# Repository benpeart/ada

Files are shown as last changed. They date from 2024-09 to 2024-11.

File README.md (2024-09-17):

# Ada
A friendly balancing robot

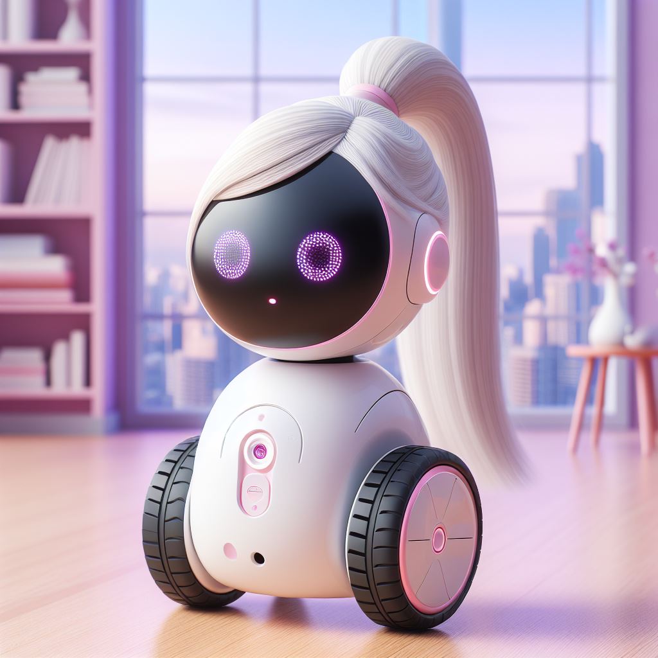
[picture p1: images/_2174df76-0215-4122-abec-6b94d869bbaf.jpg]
Ada, the friendly balancing robot


# MVP Features
* Cute - call it Ada (Lovelace)
* Two wheeled balancing robot
* Drive with a game controller
# V.Next Features
* Track person and follow them around
* Face recognition – “Hi Mom!”
* speak name, verbal interface (integrate with CoPilot/ChatGPT?)
* WebUI that allows manual navigation (virtual joystick and object avoidance)
* WebUI that shows LIDAR map with ability to tell them to go to a specific location

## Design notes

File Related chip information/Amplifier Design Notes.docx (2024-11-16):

HI-FI LM386 Stereo Amplifier : 3 Steps (with Pictures) - Instructables (https://www.instructables.com/HI-FI-LM386-Stereo-Amplifier/)

Simple Arduino Audio/Music Player with SD Card (circuitdigest.com) (https://circuitdigest.com/microcontroller-projects/arduino-audio-music-player)

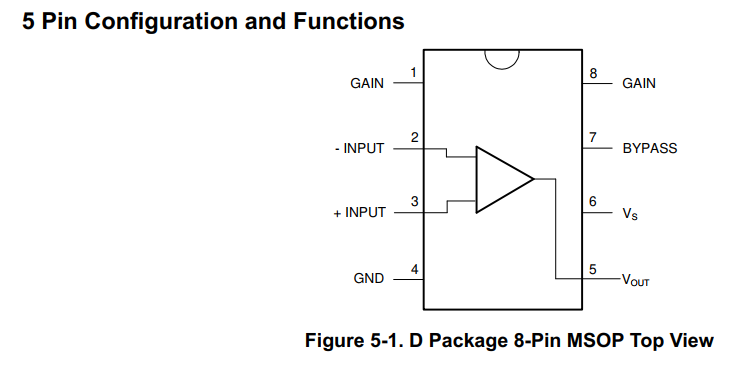
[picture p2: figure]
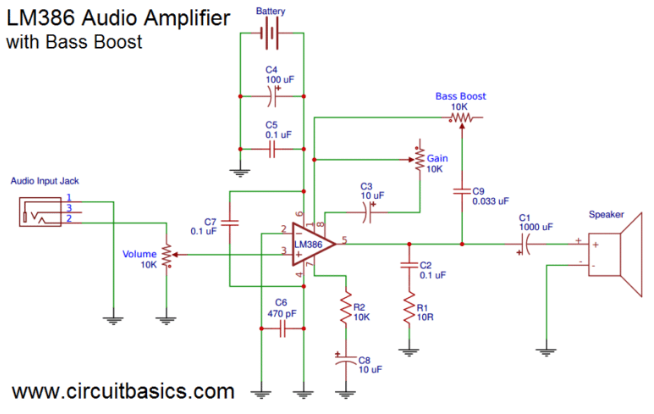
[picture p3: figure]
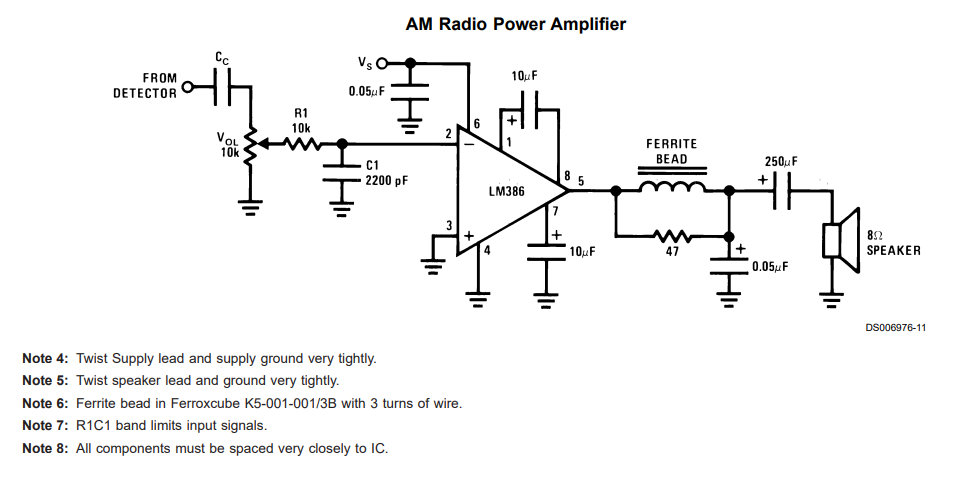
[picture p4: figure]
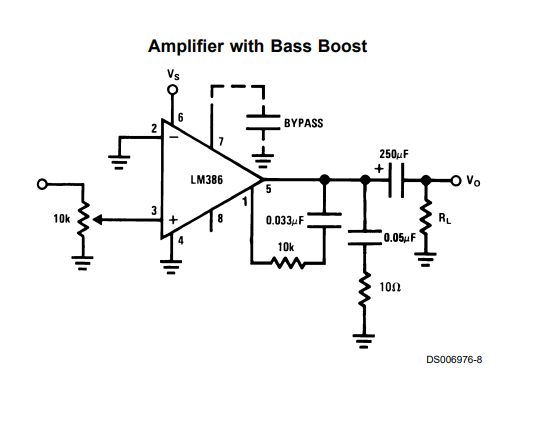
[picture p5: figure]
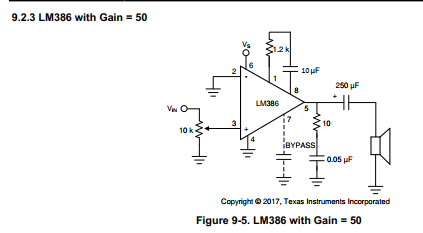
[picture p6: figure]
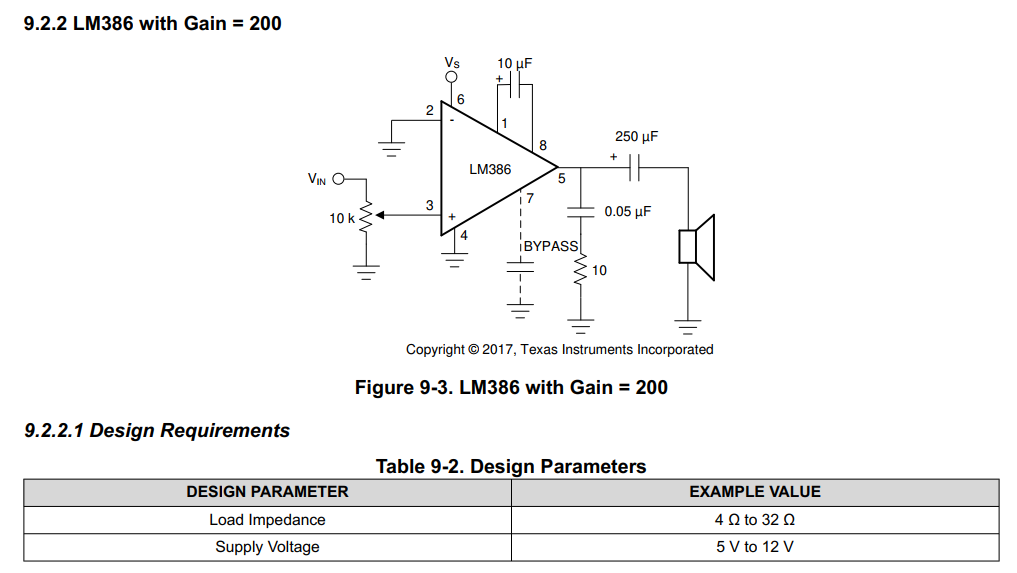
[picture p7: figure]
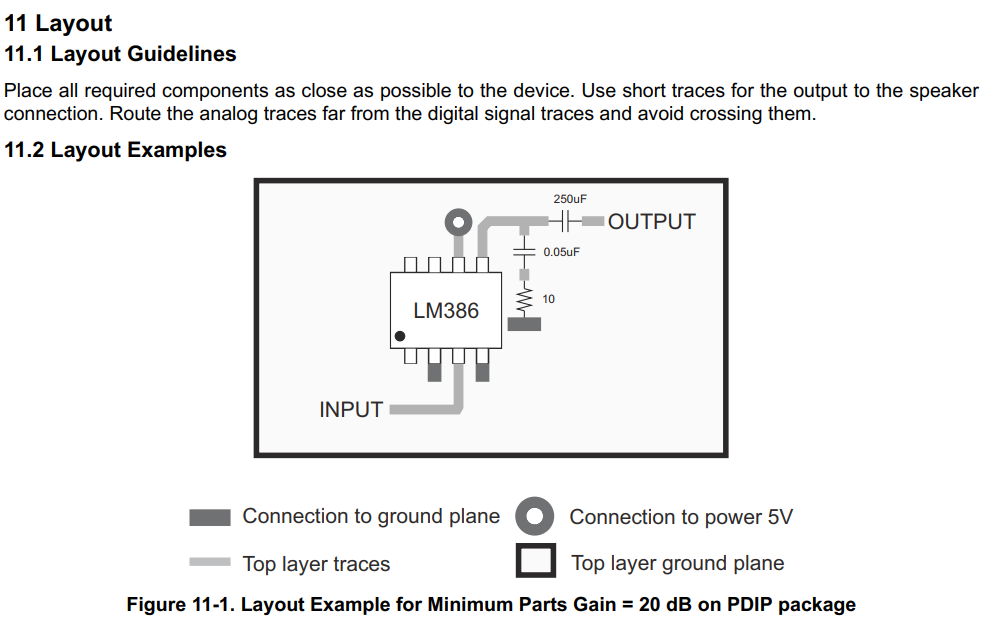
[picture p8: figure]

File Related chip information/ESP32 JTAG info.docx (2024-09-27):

## Wiring Connections (https://docs.platformio.org/en/latest/plus/debug-tools/esp-prog.html)

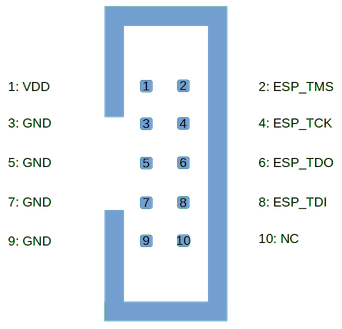
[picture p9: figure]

ESP-Prog JTAG 10-Pin Connector | PCB Header Pin | JTAG Signal | ESP32 Pin | Description
6 | 6 | TDO | GPIO15 | Test Data Out
2 | 5 | TMS | GPIO14 | Test Mode State
8 | 4 | TDI | GPIO12 | Test Data In
3 | 3 | GND | GND | Digital ground
4 | 2 | TCK | GPIO13 | JTAG Return Test Clock
1 | 1 | VDD | VDD | Positive Supply Voltage — Power supply for JTAG interface drivers

## USB configuration

1. After wiring it up, plug the ESP-Prog debugger board into a free USB port on your PC
2. Run Zadig.exe and check the “Options/List All Devices” option
3. Find “Dual RS232-HS (Interface 0)” and replace the driver with “WinUSB (v6.1.7600.16385)”
4. Find “Dual RS232-HS (Interface 0)” and replace the driver with “WinUSB (v6.1.7600.16385)”

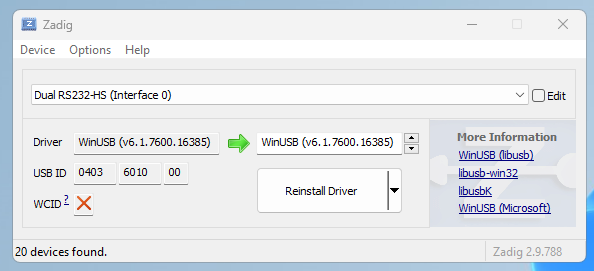
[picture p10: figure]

Add the following lines to platform.ini:

debug_tool = esp-prog

debug_init_break = tbreak setup

## Notes

Jumpers on the ESP-Prog board allow you to choose 3.3V or 5V output. It should match the power pin VDD is connected to on the ESP32.

To get it to update and debug successfully, I didn’t plug in the JTAG power wire to the ESP32 (the orange wire on pin closest to USB port). I can then plug in the regular USB port from ESP32 to PC which powers the ESP32.

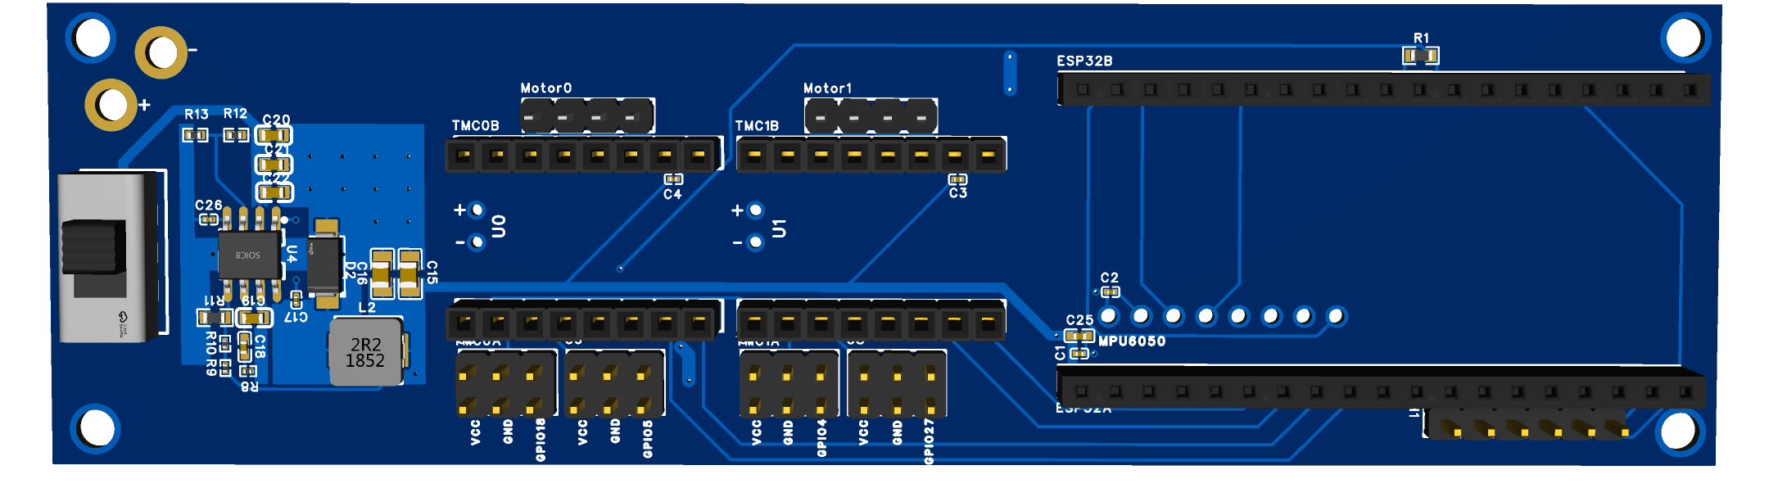
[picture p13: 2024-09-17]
Hardware/Ada PCB.png

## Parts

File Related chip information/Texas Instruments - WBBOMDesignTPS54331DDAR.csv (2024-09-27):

Part | Manufacturer | Part Number | Quantity | Price ($) | Footprint (mm²) | Description
Cboot | MuRata | GRM155R71A104KA01D | 1 | 0.01 | 3 | Cap: 100 nF Total Derated Cap: 100 nF VDC: 10 V ESR: 1 mΩ Package: 0402
Ccomp | TDK | C2012C0G1H272J060AA | 1 | 0.03 | 6.75 | Cap: 2.7 nF Total Derated Cap: 2.7 nF VDC: 50 V ESR: 0 Ω Package: 0805
Ccomp2 | Yageo | CC0805JRNPO9BN100 | 1 | 0.01 | 6.75 | Cap: 10 pF Total Derated Cap: 10 pF VDC: 50 V ESR: 0 Ω Package: 0805
Cin | TDK | C3225X7R1H106M250AC | 2 | 0.27 | 14.7 | Cap: 10 µF Total Derated Cap: 10 µF VDC: 50 V ESR: 1 mΩ Package: 1210
Cout | MuRata | GRM32ER61C476KE15L | 2 | 0.17 | 14.7 | Cap: 47 µF Total Derated Cap: 63 µF VDC: 16 V ESR: 3.04 mΩ Package: 1210
Css | MuRata | GRM033R71A822KA01D | 1 | 0.01 | 2.08 | Cap: 8.2 nF Total Derated Cap: 8.2 nF VDC: 10 V ESR: 1 mΩ Package: 0201
D1 | Fairchild Semiconductor | FSV360FP | 1 | 0.13 | 13.16 | Type: Schottky VRRM: 60 V Io: 3 A
L1 | Coilcraft | MSS1038-123MLB | 1 | 0.62 | 151.28 | L: 12 µH DCR: 36.9 mΩ IDC: 4 A
Rcomp | Vishay-Dale | CRCW040213K7FKED | 1 | 0.01 | 3 | Resistance: 13.7 kΩ Tolerance: 1.0% Power: 63 mW
Rfbb | Vishay-Dale | CRCW04021K96FKED | 1 | 0.01 | 3 | Resistance: 1.96 kΩ Tolerance: 1.0% Power: 63 mW
Rfbt | Vishay-Dale | CRCW040210K2FKED | 1 | 0.01 | 3 | Resistance: 10.2 kΩ Tolerance: 1.0% Power: 63 mW
U1 | Texas Instruments | TPS54331DDAR | 1 | 0.53 | 55.2

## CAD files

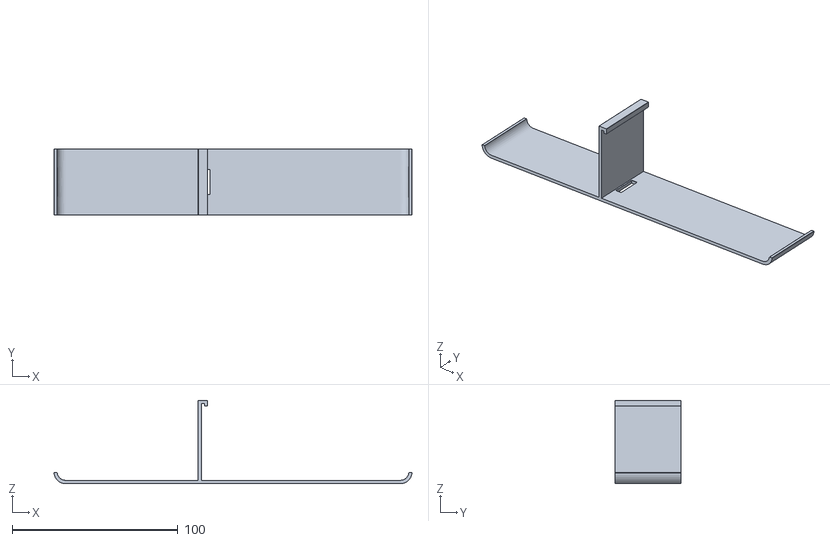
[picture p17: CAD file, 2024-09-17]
Hardware/Kickstand v13.stl
215.9 x 40.0 x 50.2

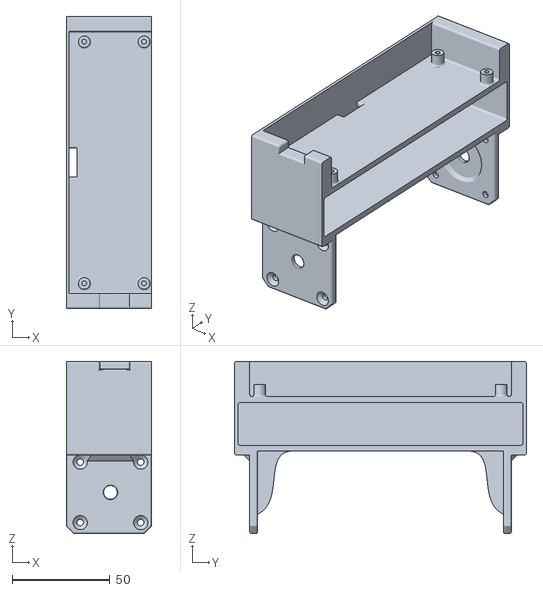
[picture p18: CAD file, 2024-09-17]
Hardware/Ada.stl
43.8 x 149.6 x 88.3

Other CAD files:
Hardware/Ada.f3d
Hardware/Frame.f3d
Hardware/Wheel.f3d

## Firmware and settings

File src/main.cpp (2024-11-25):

/*
A high speed balancing robot, running on an ESP32.

Forked and highly modified by Ben Peart. See http://github.com/benpeart/ada

Wouter Klop
wouter@elexperiment.nl
For updates, see elexperiment.nl

Use at your own risk. This code is far from stable.

This work is licensed under the Creative Commons Attribution-ShareAlike 4.0 International License.
To view a copy of this license, visit http://creativecommons.org/licenses/by-sa/4.0/
This basically means: if you use my code, acknowledge it.
Also, you have to publish all modifications.

*/

#include <Arduino.h>
#include "globals.h"
#include <gyro.h>
#include "fsm.h"
#ifdef TMC2209
#include <TMCStepper.h>
#endif // TMC2209
#include "led.h"
#include "wificonnection.h"
#include "webserver.h"
#ifdef INPUT_PS3
#include "ps3.h"
#endif // INPUT_PS3
#ifdef INPUT_XBOX
#include "xbox.h"
#endif // INPUT_XBOX
#include "debug.h"

// TMC2209 Stepper driver
#ifdef TMC2209
#define DRIVER_ADDRESS_LEFT 0b00  // TMC2209 Driver address according to MS1=LOW and MS2=LOW
#define DRIVER_ADDRESS_RIGHT 0b01 // TMC2209 Driver address according to MS1=HIGH and MS2=LOW

#define SERIAL2_PORT Serial2 // TMC2208/TMC2224 HardwareSerial port
#define SERIAL_BAUD_RATE 500000

#define MAX_CURRENT 2000 // in mA; should match capabilities of stepper motor
#define R_SENSE 0.11f    // Match to your driver
                         // SilentStepStick series use 0.11
                         // UltiMachine Einsy and Archim2 boards use 0.2
                         // Panucatt BSD2660 uses 0.1
                         // Watterott TMC5160 uses 0.075

TMC2209Stepper tmcDriverLeft(&SERIAL2_PORT, R_SENSE, DRIVER_ADDRESS_LEFT);   // Hardware Serial
TMC2209Stepper tmcDriverRight(&SERIAL2_PORT, R_SENSE, DRIVER_ADDRESS_RIGHT); // Hardware Serial
#else
// #define STEPPER_DRIVER_A4988 // Use A4988 stepper driver, which uses different microstepping settings
#define STEPPER_DRIVER_TMC2209 // Use TMC2209 stepper driver, which uses different microstepping settings

#endif // TMC2209

// Remote control structure
remoteControlType remoteControl;

// -- EEPROM
Preferences preferences;
#define PREF_VERSION 1 // if setting structure has been changed, count this number up to delete all settings
#define PREF_NAMESPACE "pref"
#define PREF_KEY_VERSION "ver"

#define BATTERY_VOLTAGE_USB 5       // the voltage when running via USB instead of the battery
#define BATTERY_VOLTAGE_LOW 20      // the voltage we warn the user
#define BATTERY_VOLTAGE_SHUTDOWN 18 // the voltage we shutdown to prevent damaging the battery
#define BATTERY_VOLTAGE_FULL 22.3   // the voltage of a full battery

float BatteryVoltage()
{
    // Measure battery voltage
#ifdef BATTERY_VOLTAGE
    const float R1 = 100000.0;        // 100kΩ
    const float R2 = 10000.0;         // 10kΩ
    const float ADC_MAX = 4095.0;     // 12-bit ADC
    const float V_REF = 3.3;          // Reference voltage
    const float ALPHA = 0.05;         // low pass filter
    static float filteredBattery = 0; // use a low-pass filter to smooth battery readings

    int adcValue = analogRead(PIN_BATTERY_VOLTAGE);
    float voltage = (adcValue / ADC_MAX) * V_REF;
    float batteryVoltage = voltage * (R1 + R2) / R2;

    // take the first and filter the rest
    if (!filteredBattery)
        filteredBattery = batteryVoltage;
    else
        filteredBattery = (ALPHA * batteryVoltage) + ((1 - ALPHA) * filteredBattery);

    // return the battery voltage
    return filteredBattery;
#endif // BATTERY_VOLTAGE
}

// ----- Main code
void setup()
{
    Serial.begin(115200);

    // Init preferences EEPROM, if not done before
    preferences.begin(PREF_NAMESPACE, false); // false = RW-mode
    if (preferences.getUInt(PREF_KEY_VERSION, 0) != PREF_VERSION)
    {
        preferences.clear(); // Remove all preferences under the opened namespace
        preferences.putUInt(PREF_KEY_VERSION, PREF_VERSION);
        DB_PRINTF("EEPROM init complete, all preferences deleted, new pref_version: %d\n", PREF_VERSION);
    }

    // initialize our LED strip and library
    LED_setup();
    LED_set(LED_BATTERY, CRGB::Green);

    // Disable steppers during startup
    pinMode(motEnablePin, OUTPUT);
    digitalWrite(motEnablePin, HIGH); // disable driver in hardware
    LED_set(LED_ENABLED, CRGB::Red);

    // setup micro stepping/serial address pins for output
    pinMode(motLeftUStepPin1, OUTPUT);
    pinMode(motLeftUStepPin2, OUTPUT);
    pinMode(motRightUStepPin1, OUTPUT);
    pinMode(motRightUStepPin2, OUTPUT);

#ifdef TMC2209
    // use TMC2209 pins MS1 and MS2 to set the correct address for Serial control
    digitalWrite(motLeftUStepPin1, LOW);
    digitalWrite(motLeftUStepPin2, LOW);
    digitalWrite(motRightUStepPin1, HIGH);
    digitalWrite(motRightUStepPin2, LOW);

    // setup a TMC2209 stepper driver
    SERIAL2_PORT.begin(SERIAL_BAUD_RATE, SERIAL_8N1, SERIAL2_RX_PIN, SERIAL2_TX_PIN); // Initialize HW UART drivers with the correct RX/TX pins
    tmcDriverLeft.begin();                                                            // Initiate pins and registeries
    tmcDriverRight.begin();                                                           // Initiate pins and registeries
    tmcDriverLeft.toff(5);                                                            // Enables driver in software (0 = driver off, 1-15 = driver enabled)
    tmcDriverRight.toff(5);                                                           // Enables driver in software (0 = driver off, 1-15 = driver enabled)

    // test the serial connections to the TMC2209
    uint8_t resultLeft = tmcDriverLeft.test_connection();
    if (resultLeft != 0)
    {
        DB_PRINTF("tmcDriverLeft.test_connection failed with error code: %d\n", resultLeft);
    }
    uint8_t resultRight = tmcDriverRight.test_connection();
    if (resultRight != 0)
    {
        DB_PRINTF("tmcDriverRight.test_connection failed with error code: %d\n", resultRight);
    }
    if (resultLeft == 0 && resultRight == 0)
    {
        tmcDriverLeft.rms_current(MAX_CURRENT);  // Set stepper current to MAX_CURRENT in mA
        tmcDriverRight.rms_current(MAX_CURRENT); // Set stepper current to MAX_CURRENT in mA

        // configure microstepping
        tmcDriverLeft.mstep_reg_select(true);  // Microstep resolution selected by MRES register instead of MS1 and MS2 pins
        tmcDriverRight.mstep_reg_select(true); // Microstep resolution selected by MRES register instead of MS1 and MS2 pins

        // enable CoolStep to save up to 75% of energy
        tmcDriverLeft.TCOOLTHRS(0xFFFF);  // Set threshold for CoolStep
        tmcDriverRight.TCOOLTHRS(0xFFFF); // Set threshold for CoolStep
        tmcDriverLeft.semin(5);           // Minimum current adjustment min = 1, max = 15
        tmcDriverRight.semin(5);          // Minimum current adjustment min = 1, max = 15
        tmcDriverLeft.semax(2);           // Maximum current adjustment min = 0, max = 15, 0-2 recommended
        tmcDriverRight.semax(2);          // Maximum current adjustment min = 0, max = 15, 0-2 recommended
        tmcDriverLeft.sedn(0b01);         // Current down step speed
        tmcDriverRight.sedn(0b01);        // Current down step speed

        // StealthChop2 guarantees that the motor is absolutely quiet in standstill and in slow motion
        // SpreadCycle provides high dynamics (reacting at once to a change of motor velocity) and highest peak velocity at low vibration
        tmcDriverLeft.en_spreadCycle(false);  // Toggle spreadCycle on TMC2208/2209/2224. false = StealthChop (low speed) / true = SpreadCycle (faster speeds)
        tmcDriverRight.en_spreadCycle(false); // Toggle spreadCycle on TMC2208/2209/2224. false = StealthChop (low speed) / true = SpreadCycle (faster speeds)
        tmcDriverLeft.pwm_autoscale(true);    // Enable automatic current scaling for stealthChop
        tmcDriverRight.pwm_autoscale(true);   // Enable automatic current scaling for stealthChop
    }

#endif // TMC2209

    // Gyro setup
    Gyro_setup(dT);

    // Connect to WiFi and setup for OTA updates
    WiFi_setup();

    // setup the AsyncWebServer and WebSocketsServer
    WebServer_setup();

    // setup the balanced controller task
    BalanceController_setup();

// Setup PS3 controller
#ifdef INPUT_PS3
    ps3_setup();
#endif

// Setup Xbox controller
#ifdef INPUT_XBOX
    Xbox_setup();
#endif

    DB_PRINTLN("Booted, ready for driving!");
}

void loop()
{
    // check the battery voltage and if necessary, inform the user
    EVERY_N_MILLISECONDS(5000)
    {
        static float batteryVoltage = BATTERY_VOLTAGE_FULL;
        batteryVoltage = BatteryVoltage();

        // check to see if we're running via USB instead of the battery
        if (batteryVoltage < BATTERY_VOLTAGE_USB)
            batteryVoltage = BATTERY_VOLTAGE_FULL;

        if (batteryVoltage < BATTERY_VOLTAGE_LOW)
        {
            LED_set(LED_BATTERY, CRGB::Yellow);
        }
        if (batteryVoltage <= BATTERY_VOLTAGE_SHUTDOWN)
        {
            DB_PRINTF("Battery voltage is critically low (%.1f). Entering deep sleep mode...\n", batteryVoltage);
            LED_set(LED_BATTERY, CRGB::Red);

            // shut off the motors
            bc.setState(Disabled::GetInstance(), 0, NULL);
            LED_loop();
            esp_deep_sleep_start(); // Enter deep sleep mode
            return;
        }
    }

    WiFi_loop();
    WebServer_loop();
    parseSerial();

    // Handle PS3 controller
#ifdef INPUT_PS3
    Ps3_loop();
#endif

    // Handle Xbox controller
#ifdef INPUT_XBOX
    Xbox_loop();
#endif

    // show any updated LEDs
    LED_loop();
}

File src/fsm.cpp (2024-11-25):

//
// Implement a Finite State Machine to track state changes. The following
// states and conditions are currently supported.
//
//  Current State	Next State	Event/Condition
//  ====================================================================
//  Disabled	Position	Robot is standing
//  Disabled	Self Right	Self right command
//  Driving	    Disabled	Disable command
//  Driving	    Disabled	Robot has fallen
//  Driving	    Disabled	Robot unable to stand
//  Driving	    Position	No speed input from controller for 2 seconds
//  Position	Disabled	Disable command
//  Position	Disabled	Robot has fallen
//  Position	Disabled	Robot unable to stand
//  Position	Driving	    Speed input from controller
//  Self Right	Disabled	Disable command
//  Self Right	Disabled	Robot has fallen
//  Self Right	Disabled	Robot unable to stand
//  Self Right	Position	Robot is standing
//

#include <Arduino.h>
#include "globals.h"
#include "fsm.h"
#include <fastStepper.h>
#include "gyro.h"
#include "led.h"
#include "PID.h"
#include "debug.h"
#include <freertos/FreeRTOS.h>
#include <freertos/task.h>
#include <freertos/semphr.h>

BalanceController bc;

#ifdef FALL_DETECTION
// Threshold for fall detection. If integral of error of angle controller is larger than this value, controller is disabled
#define angleErrorIntegralThreshold 30.0
#define angleErrorIntegralThresholdDuringSelfright angleErrorIntegralThreshold * 3
static float angleErrorIntegral = 0;
#endif // FALL_DETECTION

#define angleEnableThreshold 5.0   // If (absolute) robot angle is below this threshold, enable control
#define angleDisableThreshold 70.0 // If (absolute) robot angle is above this threshold, disable control (robot has fallen down)

// -- PID control
float dT = dT_MICROSECONDS / 1000000.0;

#define PID_ANGLE_MAX 12
PID pidAngle(cPID, dT, PID_ANGLE_MAX, -PID_ANGLE_MAX);
#define PID_POS_MAX 35
PID pidPos(cPD, dT, PID_POS_MAX, -PID_POS_MAX);
#define PID_SPEED_MAX 27
PID pidSpeed(cP, dT, PID_SPEED_MAX, -PID_SPEED_MAX);

// make these global so we can use them in webui.cpp
uint32_t tNowMs;
float pidAngleOutput;
float pidPosOutput;
float pidSpeedOutput;

// Use 'Expodential Smoothing' to improve driving behaviour by preventing abrupt changes in speed or direction
float speedAlphaConstant = 0.1; // how fast it reacts to inputs, higher = softer (between 0 and 1, but not 0 or 1)
float steerAlphaConstant = 0.1; // how fast it reacts to inputs, higher = softer (between 0 and 1, but not 0 or 1)
extern float maxStepSpeed;

uint8_t microStep = 0;
float maxStepSpeed = 1500;

// -- Stepper motor
// ----- Interrupt functions -----
portMUX_TYPE timerMux = portMUX_INITIALIZER_UNLOCKED;

void IRAM_ATTR motLeftTimerFunction()
{
    portENTER_CRITICAL_ISR(&timerMux);
    motLeft.timerFunction();
    portEXIT_CRITICAL_ISR(&timerMux);
}
void IRAM_ATTR motRightTimerFunction()
{
    portENTER_CRITICAL_ISR(&timerMux);
    motRight.timerFunction();
    portEXIT_CRITICAL_ISR(&timerMux);
}

fastStepper motLeft(motLeftStepPin, motLeftDirPin, 0, motLeftTimerFunction);
fastStepper motRight(motRightStepPin, motRightDirPin, 1, motRightTimerFunction);

void setMicroStep(uint8_t uStep)
{
    if (microStep == uStep)
        return;

    microStep = uStep;
    motLeft.microStep = uStep;
    motRight.microStep = uStep;
#ifdef TMC2209                        // Use TMC2209 stepper driver, which uses different microstepping settings
    tmcDriverLeft.microsteps(uStep);  // Set microsteps per step
    tmcDriverRight.microsteps(uStep); // Set microsteps per step
#else
#ifdef STEPPER_DRIVER_TMC2209
    uint8_t ms1, ms2;
    switch (uStep)
    {
    case 8:
        ms1 = LOW;
        ms2 = LOW;
        break;
    case 16:
        ms1 = HIGH;
        ms2 = HIGH;
        break;
    case 32:
        ms1 = HIGH;
        ms2 = LOW;
        break;
    case 64:
        ms1 = LOW;
        ms2 = HIGH;
        break;
    }
    digitalWrite(motLeftUStepPin1, ms1);
    digitalWrite(motLeftUStepPin2, ms2);
    digitalWrite(motRightUStepPin1, ms1);
    digitalWrite(motRightUStepPin2, ms2);

#else
    // input:                     1 2 4 8 16 32
    // uStep table corresponds to 0 1 2 3 4  5  in binary on uStep pins
    // So, we need to take the log2 of input
    uint8_t uStepPow = 0;
    uint8_t uStepCopy = uStep;
    while (uStepCopy >>= 1)
        uStepPow++;

    digitalWrite(motLeftUStepPin1, uStepPow & 0x01);
    digitalWrite(motLeftUStepPin2, uStepPow & 0x02);
    digitalWrite(motRightUStepPin1, uStepPow & 0x01);
    digitalWrite(motRightUStepPin2, uStepPow & 0x02);

#ifdef STEPPER_DRIVER_A4988 // The lookup table for uStepping of the 4988 writes for some reason all three pins high for 1/16th step
    if (uStep == 16)
    {
        digitalWrite(motLeftUStepPin1, HIGH);
        digitalWrite(motLeftUStepPin2, HIGH);
        digitalWrite(motRightUStepPin1, HIGH);
        digitalWrite(motRightUStepPin2, HIGH);
    }
#endif
#endif // STEPPER_DRIVER_TMC2209
#endif // TMC2209
}

// Actual balance + controller computations
void balanceLogic(BalanceController *controller, float filterAngle)
{
#ifdef DEBUG_SPINNERS
    const char *spinner = "|/-\\";
    static int i = 0;
    DB_PRINTF("\r%c", spinner[i]);
    i = (i + 1) % sizeof(spinner);
#endif // DEBUG_SPINNERS

    // calculate the correction needed to hit our target setpoint
    pidAngle.input = filterAngle;
    pidAngleOutput = pidAngle.calculate();

    controller->avgMotSpeedSum += pidAngleOutput / 2;
    controller->avgMotSpeedSum = constrain(controller->avgMotSpeedSum, -maxStepSpeed, maxStepSpeed);

    // add in steering input
    motLeft.speed = controller->avgMotSpeedSum + controller->smoothedSteer;
    motRight.speed = controller->avgMotSpeedSum - controller->smoothedSteer;

    // Dynamically switch microstepping to achieve even more insane speeds
#ifdef DYNAMIC_MICROSTEPPING
    float absSpeed = abs(controller->avgMotSpeedSum);

    if (absSpeed > (150 * 32 / microStep) && microStep > 1)
        microStep /= 2;
    if (absSpeed < (130 * 32 / microStep) && microStep < 32)
        microStep *= 2;

    setMicroStep(microStep);
#endif // DYNAMIC_MICROSTEPPING
}

Disabled *Disabled::GetInstance()
{
    static Disabled m_singleton;
    return &m_singleton;
}

void Disabled::enter(BalanceController *controller, float filterAngle, remoteControlType *remoteControl)
{
    // Used ensure we are out of the 'enabled' zone before exiting state Disabled if it was triggered by the controller.
    // Otherwise robot will immediately enter the "Position" mode when it detects we're still standing.
    if (remoteControl && remoteControl->disableControl)
    {
        DB_PRINTLN("Disabled::enter - set needToExitEnableZone");
        needToExitEnableZone = true;
        remoteControl->disableControl = false; // Reset single action bool
    }

    digitalWrite(motEnablePin, HIGH); // disable driver in hardware
    LED_set(LED_ENABLED, CRGB::Red);
    controller->avgMotSpeedSum = 0;
    motLeft.speed = 0;
    motRight.speed = 0;
}
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

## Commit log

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2018-11-10 PCB updates: increased 24V trace thickness, added a via (or rather added trace to via) in that signal, and added stepper motor enable pull-up to 3V3.
    [pendulumRobotModule.kicad_pcb, pendulumRobotModule.sch]
2018-11-12 Slight update to FrameB: second screw hole for PCB was missing. Also, added a cut-out, such that the stepper motor can be mounted.
    Also, STL files have been added for 3D-printable parts.
    [BatteryCase v1.stl, FrameA1.stl, FrameA2.stl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]
2018-11-12 Changed 10uF cap to 1uF. Also, changed text on bottom layer to point to the correct reposityor.
    [pendulumRobotModule.kicad_pcb, pendulumRobotModule.sch]
2018-11-13 Updated readme for PCB
    [pendulumRobotModule.kicad_pcb]
2018-11-13 Fixed BOM table (hopefully)
2018-11-14 Updated PCB readme.
    [pendulumRobotModule.sch]
2018-11-15 Somewhat improved IMU init. Also, closing #6, as this idea didn't seem to work: when moving the robot to an upright position, a relatively high acceleration is measured, causing the angle from accele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
    [main.cpp]
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2018-11-17 Fixing PCB readme pictures
2018-12-14 Added IRAM_ATTR to stepper motor step function, solves crash during web page load. Closing #4
2019-01-27 Updated README.md Fixed max wifi-key-length to 63 chars. Replaced EEPROM-lib by Preferences-lib. You have to reenter all settings! Added pref_version. Now it is possible to increment pref_version to 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
    [main.cpp]
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2019-02-03 Updated AsyncTCP and arduinoWebsockets libraries. Also, moved wireless tasks (IBus and wsServer) back to the main loop (core 1). While running on core 0, i2c issues were created due to the i2c bus be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
    [main.cpp]
2019-02-03 Updated instructions for PCB (auxiliary header pinout), and some general instructions on stepper current adjustment and IMU calibration.
2019-02-07 PCB updated to version 1.2: added RX pulldown resistor and 5V buffer capacitor (both optional). Added some markings for buck converter. Web interface now has a fancy option for logging data (plotTest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
    [pendulumRobotModule.kicad_pcb, pendulumRobotModule.sch]
2019-02-08 Noise insertion implementation
2019-02-13 Some initial work on system identification in the frequency domain
    [logData (12).csv, logData.csv]
2019-02-18 First system ID working. R parameter added to web interface (controls amount of setpoint used for error signal of PID controller)
    [logData (13).csv, logData (14).csv, logData (15).csv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]
2019-04-29 Added ace.js to ESP32 data folder. So far, when using access point to connect to robot, the /edit page wouldn't work, unless ace.js was previously cached. Now it should work fine.
2019-06-18 Added PPM-input Added speedFactor and steerFactor to set how strong it reacts to inputs Set default maxStepSpeed to 1500 Updated readme for stepper recommendation
2021-02-19 Initial simulation of system. Started with simple pendulum. Goal is to have a dynamical model of the system, such that I can simulate sensor behavior.
2021-02-20 Fixed bug in y position of m2. Animation with rolling wheel (with spokes). Added fifth variable, which represents angle of wheel.
2021-03-01 Added feature which allows to drive with robot when it is lying down. Disabled microstepping as I'm now using TMC2100 drivers.
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2021-04-14 Initial work on getting self right and disable buttons to work via wifi control. Still quite buggy
    [main.cpp]
2021-04-17 Fixed bug in IBus code: if no receiver was connected, robot would still read speed command. IBus active flag is now set to true if a first message has been received.
    [main.cpp]
2021-10-06 Added a new frame (frameC) which can house a 3S LiPo, and has improved robustness. Also it still self-rights with this frame.
    [FrameC v8.f3d, FrameC.stl]
2022-03-30 Implemented bluetooth control with cheap PS3 controller. Also, changed partition table, as new code (from PS3 controller) causes the default partition for code to be too small.
    [partition_smaller_spiffs.csv]
2022-06-07 Cleaned up library dependencies (using PlatformIO library manager now). Made PS3 control optional (can be commented out) as it takes up a lot of space. Downgraded to ESP IDF v3.4.0 as 4.3.0 (latest) 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
    [main.cpp]
2022-06-08 Implemented battery voltage readout. ADC is configured correctly, calibrated, and measured value is sent over to web page.
    [main.cpp]
2022-06-08 Added partition table. Some small changes for handling serial commands
    [partition_no_ota.csv]
2022-06-10 Bluetooth MAC address is now printed correctly on startup
    [main.cpp]
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2022-06-13 changed velocity presets
    lower linear speed
    increased rotational speed
    added offset control to adjust for asymmetric speed forward/reverse
    [main.cpp]
2022-06-20 update web page formatting
    repaired tag and inserted <div> in the <body> to switch to style
2022-08-31 Implemented fall detection. If stepper motors are slipping, but robot doesn't react, the controller will disable itself.
    [main.cpp]
2022-08-31 PCB v1.3 update. Added power switch, battery connector, and status LEDs.
    [pendulumRobotModule.kicad_pcb, pendulumRobotModule.sch]
2022-08-31 Some slight updates to PCB, also updated readme for PCB
    [pendulumRobotModule.kicad_pcb, pendulumRobotModule.sch]
2022-08-31 Some final touches on the PCB
    [pendulumRobotModule.kicad_pcb]
2022-09-03 Some final touches to PCB / documentation of PCB
    [pendulumRobotModule.sch]
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2022-10-19 Added LEDs in software. Small bugfix, self right sometimes not working correctly, fixed by reseting angle error integral after self right is complete.
    [main.cpp]
2023-08-27 Updated PCB design files to Kicad 7. Added cut-out for stepper motor cable pass-through. Updated PCB version to v1.4. Connected LEDS to gpio 33 and 26, as old connections were used for USB TX/RX.
    [pendulumRobotModule.kicad_pcb]
2023-09-22 Added compatibility for A4988 stepper driver, which has a somewhat different pattern for microstepping
2023-09-25 Added laser cut frame. Updated readme instructions for laser cut frame, PCB v1.4, and bluetooth control.
    [frameLaserCut3 v16.f3d]
2023-10-07 Upload New File
    [Framec_v13.f3d]
2023-10-13 Fixed a bug in the serial interface. Updated documentation for calibrating/setting WiFi settings.
    [main.cpp]
2024-09-14 Update to latest version of AsyncTCP and ESPAsyncWebServer Update to latest version of espressif32 platform Update fastStepper.cpp to support GPIO pins between 32 and 40 Add Xbox controller support A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
2024-09-14 Remove streaming library and use DB_PRINT* instead so our releases don't have all the debug info in them Remove FlySkyIBus code Remove motor current code (will use the TMC2209 library if it is needed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
2024-09-15 in plotTest.htm, open a web socket on load and disconnect to make it more robust fix a bug that prevented plotting from working by externing a single plot structure in globals.h Call Xbox_setup() so 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
    [globals.h, main.cpp]
2024-09-17 restructure directories to work better with vscode
    [Ada.fzz, Ada.stl, ESP32 pin assignments.xlsx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]
2024-09-17 Remove lots of unused files from the original project. Replace with Ada specific files where needed.
    [BatteryCase v1.f3d, BatteryCase v1.stl, FrameA v1.f3d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]
2024-09-18 Now have Home, Settings, Control, Tune, Credits pages Home - pretty picture of Ada with links to other pages Settings - let you sent the robot name, wifi settings, stepper settings, calibrate gyro an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
2024-09-19 Update WiFi logic so that it will reconnect if it ever disconnects. Add battery voltage logic for when we add that to the PCB. Move bluetooth address variable into ps3.cpp as nothing else needs it.
2024-09-27 Add the TMCStepper library to enable controlling the features of the TMC2209 like CoolStep to save 75% energy and StealthChop to make the stepper motors silent at low speed. Replace the LED logic wit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
    [Ada.fzz, ESP32 pin assignments.xlsx, Texas Instruments - WBBOMDesignTPS54331DDAR.csv]
2024-09-27 More code refactoring. Split out the MPU6050 gyroscope code into separate gyro.h/cpp files.
2024-10-01 Remove more dead code and variables to improve readability of the code Switch boolean values to use true/false to improve readability of the code Clean up and document Expodential Smoothing code, var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
    [ESP32 pin assignments.xlsx]
2024-11-06 Split up webserver and wifi/ota so we can remove the webserver from release builds as it is only needed for development/setup. Enable battery support as we have it in the latest PCB
2024-11-06 Update pin assignments to match the V2 hardware.
    NOTE: The TMC2209 code is currently not functional with V2 hardware.
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2024-11-14 Lower the maximum angle allowed by pidSpeed to prevent it from tipping over when you release the throttle. Simplify the removal of optional features. Instead of removing calls to functions, just make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
    [globals.h, main.cpp, webserver.cpp]
2024-11-16 Lower PID_SPEED_MAX so we are less likely to flip over with extreme accel/decel commands. Remove unused "ANGLE_ONLY" controlType. Change "Xbox connected" LED to be RED/GREEN to reflect connectivity.
    Implement a Finite State Machine to track balancing state changes. The following
    states and conditions are currently supported.
    Current State Next State Event/Condition
    ====================================================================
    Disabled Position Robot is standing
    Disabled Self Right Self right command
    Driving Disabled Disable command
    Driving Disabled Robot has fallen
    Driving Disabled Robot unable to stand
    Driving yPosition No speed input from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
    [fsm.cpp, globals.h, main.cpp]
2024-11-16 Update Ada EasyEDAPro file with the V2 hardware design. Update the #SP32 pin assignments to match the V2 hardware. Update the (unused) Amplifier Design Notes.
    [ESP32 pin assignments.xlsx]
2024-11-21 Output finite state machine changes in DEBUG mode Only transition states if they actually change
    Add a battery LED that shows green if "healthy," yellow if low and red if critical.
    Add logic to detect if we are running via USB or the battery.
    If powered by the battery, added logic to automatically disable Ada and enter deep sleep mode to prevent damaging a critically low battery.
    [fsm.cpp, globals.h, main.cpp]
2024-11-23 Let the compiler generate default constructors where needed Fix some state transitions to deal with bugs: - standing up bot manually works front to back but not back to front - standing up bot manual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
    [fsm.cpp, main.cpp]
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2024-12-02 Add Ada Fusion 360 file used to create the frame and wheels.
    [Ada.f3d]
2024-12-02 Add EasyEDA Pro file used to create the PCB Add finite state machine transition table Add alternate firmware partition tables (currently not used)
    [Ada transition state table.xlsx, partition_no_ota.csv, partition_smaller_spiffs.csv]
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
